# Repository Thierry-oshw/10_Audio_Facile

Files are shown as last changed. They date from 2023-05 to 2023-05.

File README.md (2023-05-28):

# 10_Audio_Facile

Le module Audio_Facile permet d'amplifier un signal électrique analogique pour piloter un haut-parleur.

La licence est celle du CERN Open Hardware Licence version 2; CERN-OHL-P ; permissive.
Le fichier de cette license est présent dans le répertoire: cern_ohl_p_v2.txt

# Photos

10_Audio_Facile photo du dessus du module version .

# Schéma et fonctionnement

Ci-joint le schéma de la version de 
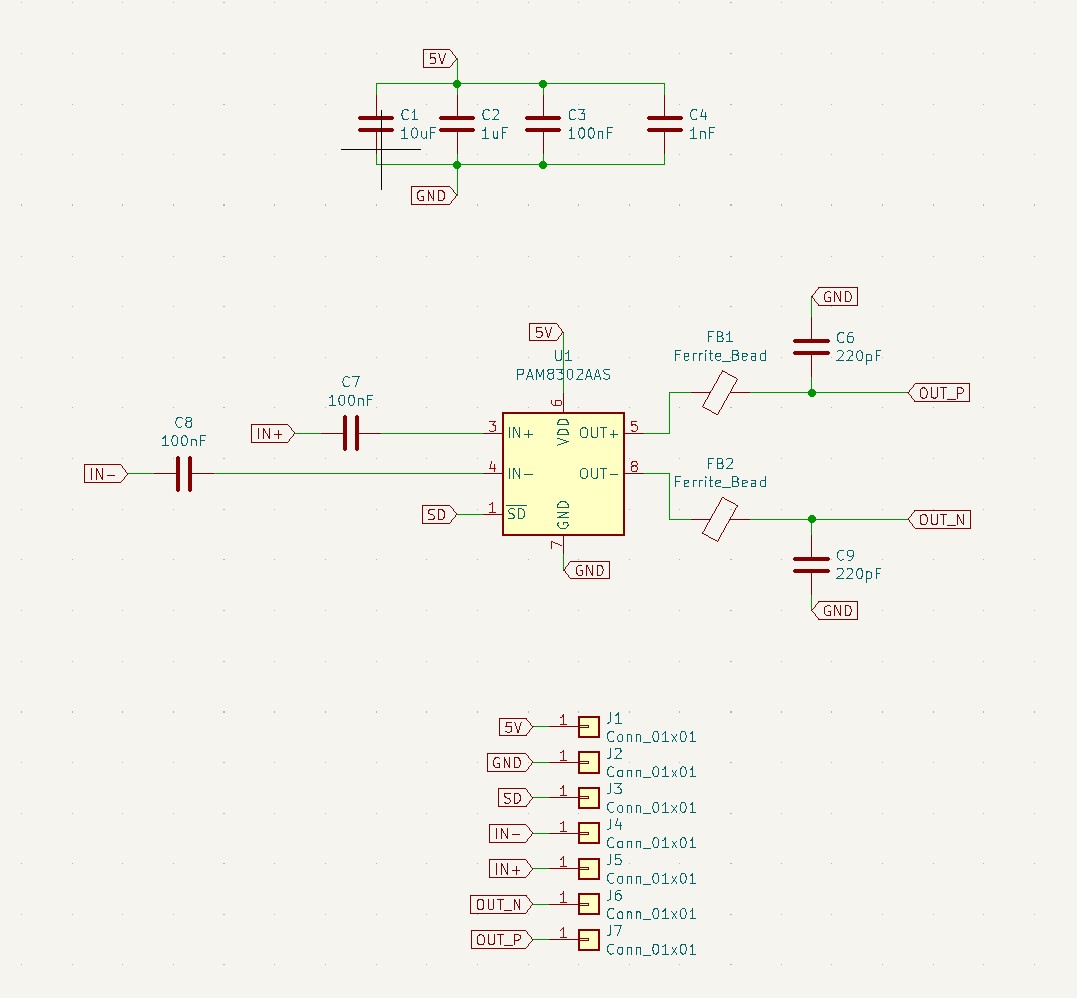
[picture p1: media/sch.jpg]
10_Audio_Facile schéma du module


Le module est basé sur la puce PAM
Il faut l'alimenter avec une tension 5V +-5% (typiquement celle de l'USB classique) sur la pin Vext. (Ne pas oublier GND bien sûr).

## Fonctionnalités
- Petit (23x18 mm)
- Faible coût (2 couches avec composants d'un seul côté)
- Connecteur avec pas de 2.54 mm + empreinte crénelée pour connexion carte à carte

## Outils utilisés

- [Kicad V6](https://www.kicad.org/)

## Fabrication du circuit

Ce circuit a été testé de fond en comble sur de nombreux projets

## Contributeurs

- Thierry Orlandi ([Hardware Freelance](https://www.linkedin.com/in/thierry-orlandi))
- Yohann Belair ([R&D Freelance](https://github.com/ciborg971))

## Licence
[CERN Open Hardware Licence Version 2](https://github.com/Thierry-oshw/10_Audio_Facile/blob/main/LICENSE.txt)

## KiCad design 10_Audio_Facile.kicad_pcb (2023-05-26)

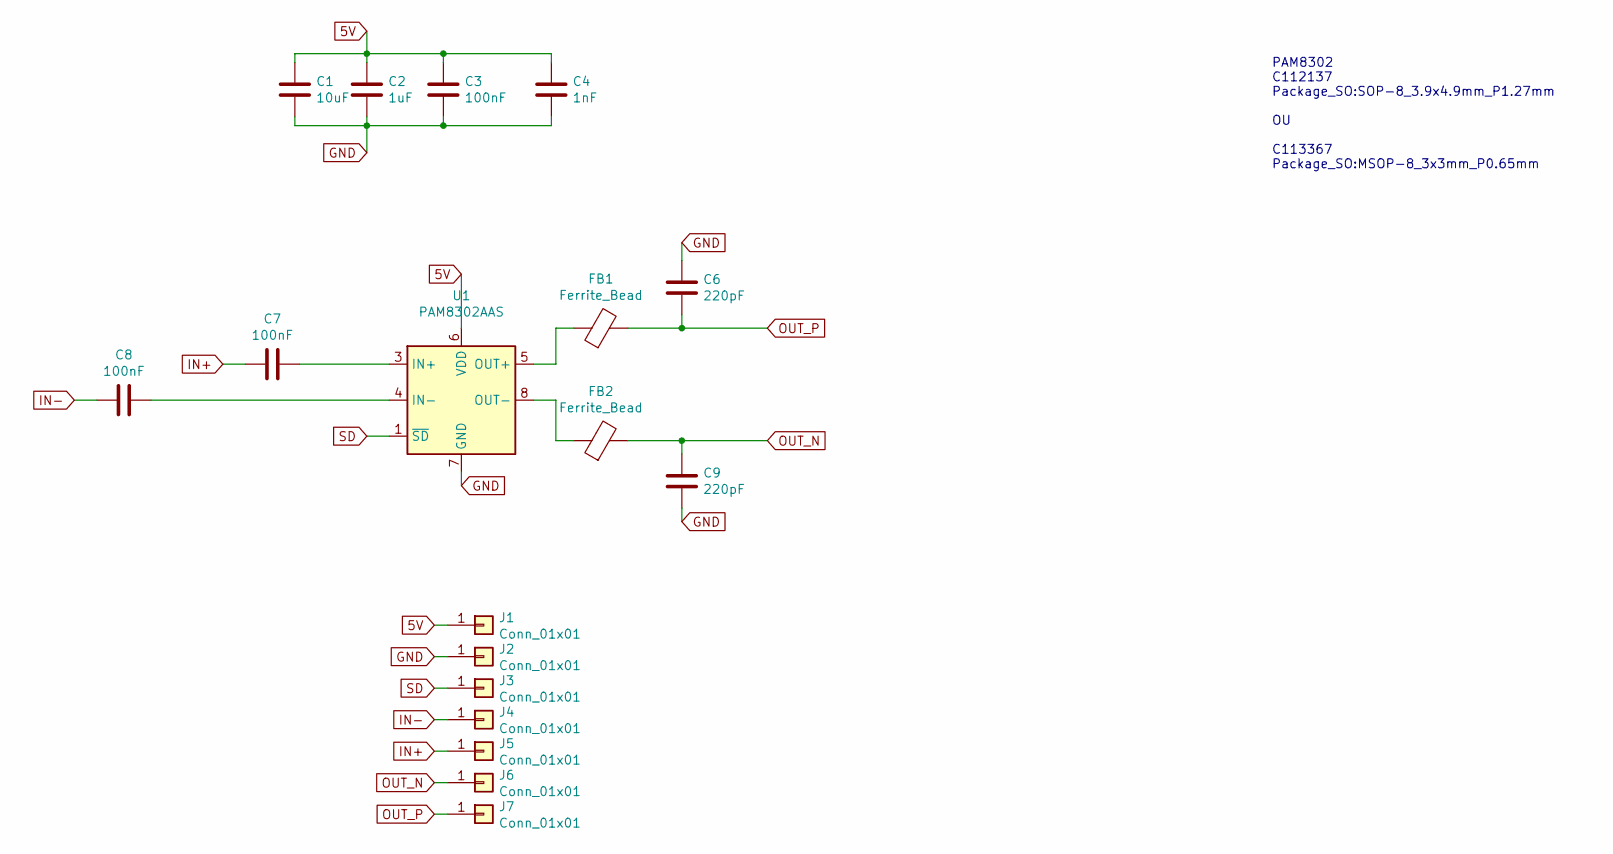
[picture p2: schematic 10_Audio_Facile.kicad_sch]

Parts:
C1: 10uF; C_1210_3225Metric; LCSC C39232
C2: 1uF; C_0603_1608Metric; LCSC C15849
C3, C7, C8: 100nF; C_0603_1608Metric; LCSC C14663
C4: 1nF; C_0603_1608Metric; LCSC C1588
C6, C9: 220pF; C_0603_1608Metric; LCSC C1603
FB1, FB2: Ferrite_Bead; L_0603_1608Metric; LCSC C85824
J1, J2, J3, J4, J5, J6, J7: Conn_01x01; Castellated_conn
U1: PAM8302AAS; SOP-8_3.9x4.9mm_P1.27mm; LCSC C112137

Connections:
5V: C1.2, C2.2, C3.2, C4.2, J1.1, U1.6 (VDD)
GND: C1.1, C2.1, C3.1, C4.1, C6.2, C9.1, J2.1, U1.7 (GND)
IN+: C7.2, J5.1
IN-: C8.2, J4.1
unnamed: C7.1, U1.3 (IN+)
unnamed: C8.1, U1.4 (IN-)
unnamed: FB1.1, U1.5 (OUT+)
unnamed: FB2.1, U1.8 (OUT-)
OUT_N: C9.2, FB2.2, J6.1
OUT_P: C6.1, FB1.2, J7.1
SD: J3.1, U1.1 (~SD)

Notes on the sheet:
PAM8302 C112137 Package_SO:SOP-8_3.9x4.9mm_P1.27mm OU C113367 Package_SO:MSOP-8_3x3mm_P0.65mm

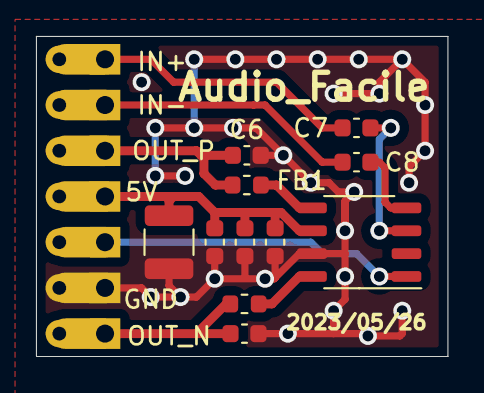
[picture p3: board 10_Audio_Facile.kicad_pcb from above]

Board: 2 copper layers, 22.9 x 17.8 mm, 18 parts (0 on the bottom side), 11 nets.

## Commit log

2021-04-05 premier jet
    [10_Audio_Facile-B_Cu.gbr, 10_Audio_Facile-B_Fab.gbr, 10_Audio_Facile-B_Mask.gbr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]
2021-05-26 suppression résistances entrées
    schéma et routage à jour
    raf: optimisation taille de la carte
    [10_Audio_Facile-B_Cu.gbr, 10_Audio_Facile-B_Fab.gbr, 10_Audio_Facile-B_Mask.gbr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]
2021-07-24 maj split librairies
    [10_Audio_Facile.kicad_pcb, 10_Audio_Facile.sch]
2021-08-02 changement date + generation gerber et fichiers de fabrication
    [10_Audio_Facile-B_Cu.gbr, 10_Audio_Facile-B_Fab.gbr, 10_Audio_Facile-B_Mask.gbr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]
2021-09-14 maj des empreintes pcb
    [10_Audio_Facile.kicad_pcb]
2023-05-18 maj kicad v6
    maj projet
    maj symboles + empreintes
    placement plus compact.
    [10_Audio_Facile.kicad_pcb, 10_Audio_Facile.kicad_sch, 10_Audio_Facile.sch]
2023-05-19 maj placement routage + fabrication
    [10_Audio_Facile-B_Cu.gbl, 10_Audio_Facile-B_Cu.gbr, 10_Audio_Facile-B_Mask.gbr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]
2023-05-26 ajout in+
    [10_Audio_Facile.kicad_pcb, 10_Audio_Facile.kicad_sch]
